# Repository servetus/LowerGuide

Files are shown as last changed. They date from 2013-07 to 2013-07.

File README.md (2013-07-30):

Replacement Lower Guide Plate for the Truvativ X-Guide Chain Guide
==================================================================

This bicycle part is intended to be a replacement part for what's called the 'Lower Guide Plate' portion of the Truvativ X-Guide Chain Guide. The function of this part is to guide a loose chain back onto the gears should it come loose. Because of its position on the bike it is prone to failure. Unfortunately Truvativ has not made replacements widely available for this non-essential part. 

Tested using Makerbot Thing-o-matic using ABS plastic.

Available on Thingiverse at: http://www.thingiverse.com/thing:121543

Printing Notes
--------------

This design has a hole for a 2.75mm screw. However, it is also recommend that you print with some 1 or 2 shells as normal use for this bike part can be pretty stressful. This can make fitting to the screw a little challenging. Four versions of the stl file areincluded with varying hole sizes. You can also modify the HOLE_RADIUS constant in the SCAD file to your liking.

Included Files
--------------

lowerguide.scad - OpenSCAD source file for those wishing to modify the design.
lowerguide_3_0.stl - STL file. Ready for print with a 3.0mm hole. Recomended for printing with 1-2+ shells.
lowerguide_2_9.stl - STL file. Ready for print with a 2.9mm hole. Recomended for printing with 0-1 shells.
lowerguide_2_8.stl - STL file. Ready for print with a 2.8mm hole. Recomended for printing with 0 shells.
lowerguide_2_75.stl - STL file. Ready for print with a 2.75mm hole. Recomended for printing with 0 shells and very precise printers.

README.md - This file

License
-------

This work by Jordan Andersen licensed under the Creative Commons Attribution 3.0 Unported License. To view a copy of this license, visit http://creativecommons.org/licenses/by/3.0/

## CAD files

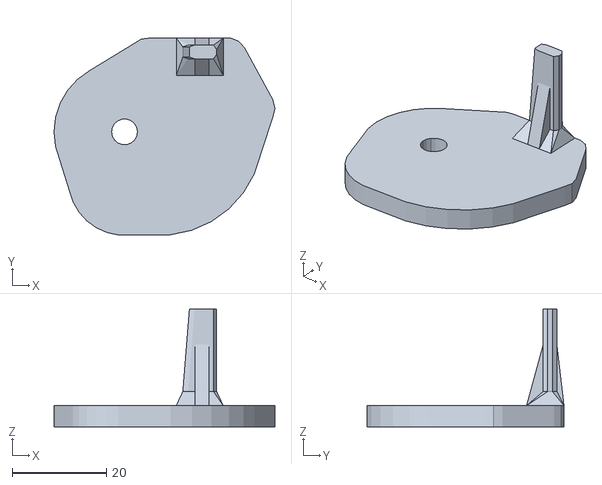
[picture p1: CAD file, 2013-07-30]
lowerguide_2_75.stl
47.0 x 41.9 x 25.0

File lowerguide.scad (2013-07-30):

//---------------------------------------------------------------------------------------------------
// This work by Jordan Andersen licensed under the Creative Commons Attribution 3.0 Unported License.
// To view a copy of this license, visit http://creativecommons.org/licenses/by/3.0/
//---------------------------------------------------------------------------------------------------
//
// Replacement Lower Guide Plate for the Truvativ X-Guide Chain Guide
//
//---------------------------------------------------------------------------------------------------
SHIELD_HEIGHT = 4.5;
HOLE_RADIUS = 2.75;
POST_HEIGHT = 25;

POST_WIDTH_TOP = 4;
POST_WIDTH_BOTTOM = 6;
POST_POSITION = [12.6, 17.5, 0];
POST_ROUNDING_RADIUS = 1;


//---------------------------------------------------------------------------------

//The shield portion of the part. Form is not super strongly connected to function.
module shield()
{
    hull()
    {
         cylinder(r=15, h=SHIELD_HEIGHT, center=false);
    
        translate([7.5, 0, 0]) difference()
        {
            
            cylinder(r=22, h=SHIELD_HEIGHT, center=false);  
            union()
            {     
                translate([0, 0, -2]) cube([100,25,9]);
                translate([-25, -50, -2]) cube([25,100,9]);
            }
        }

        translate([0, -10, 0])  cylinder(r=12, h=SHIELD_HEIGHT, center=false);

        translate([28, 5, 0])  cylinder(r=4, h=SHIELD_HEIGHT, center=false);
        translate([22, 16, 0])  cylinder(r=4, h=SHIELD_HEIGHT, center=false);
        translate([5, 16, 0])  cylinder(r=4, h=SHIELD_HEIGHT, center=false);
    }

}

module hole()
{   
    cylinder(r=HOLE_RADIUS, $fs=1, h=50, center=true);   
}

//*** RED ***
//The post portion of the part. The top is a little thinner than the base to give it 
//a nice slope to allow it to fit in another part.
module post()
{
    rotate( a = 90, v=[1,0,0]) minkowski()
    {
        rotate( a = 90, v=[1,0,0]) cylinder(r=POST_ROUNDING_RADIUS, h=0.0001);
        linear_extrude(height = 1)
        {
            polygon(points=[
                            [0,0],
                            [POST_WIDTH_BOTTOM,0],
                            [POST_WIDTH_BOTTOM,POST_HEIGHT],
                            [POST_WIDTH_BOTTOM - POST_WIDTH_TOP,POST_HEIGHT]
                          ], 
                   paths=[[0,1,2,3]]);
        }
    }
}

//Part minus the fillet
module part()
{
    difference()
    {
         color("yellow", 0.8) shield();
         hole();
    }
    color("red") translate(POST_POSITION) post();
}

//*** BLUE ***
//Fillet on the post. Takes a region around the base of the post and fills
//in the concave portion. 
module fillet()
{
    hull()
    {
        intersection()
        {
            part();
            translate([11, 12, 2.5]) cube([10, 10, 5]);    
        }
    }
    hull()
    {
        intersection()
        {
            part();
            translate([15, 12, 2.5]) cube([3, 10, 15]);    
        }
    }


}

//Final part. Fillet added back in.
module filleted_part()
{
    part();
    color("blue") fillet();
}

//Some spacers to aid visualization
module debugging()
{
    translate([HOLE_RADIUS+ 15, -50, SHIELD_HEIGHT]) cube([5, 100, 6]);
    translate( [-50, HOLE_RADIUS, SHIELD_HEIGHT]) cube([100, 11, 6]);
}

filleted_part();
//color("skyblue") debugging();

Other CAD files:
lowerguide_2_8.stl
lowerguide_2_9.stl
lowerguide_3_0.stl

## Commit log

2013-07-30 Initial commit.
    [lowerguide.scad]
2013-07-30 Adding STL files.
    [lowerguide_2_75.stl, lowerguide_2_8.stl, lowerguide_2_9.stl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]
